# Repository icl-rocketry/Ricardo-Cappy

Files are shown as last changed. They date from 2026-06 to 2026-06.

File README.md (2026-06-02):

Hi. Welcome to the repo for Ricardo-Cappy.

Ricardo-Cappy is a custom HAT (Hardware Attached on Top) for the Raspberry Pi 5 to be used on the Payload lander for the 2026 ICLR launch.

It contains IMU sensors based on Ricardo-PickleRick, wirecutter modules, motor drivers for deploying landing legs, GPS and Radio capabilities as well as power systems for both the Raspberry Pi and the onboard components.

Contents:

-Hardware - contains the KiCad schematics and PCB layouts for Ricardo-Cappy, including symbols and footprints for parts not in the ICLR library. This is necessary for viewing and editing the KiCad files on your own device. 

To use the hardware files:
1. Install the ICLR symbol and footprint library (see their repo for detailed instructions, I forgot the link but you can use google)
2. Clone the repository onto your computer.
3. Install my custom libraries into KiCad (see instructions in KiCad documentation)

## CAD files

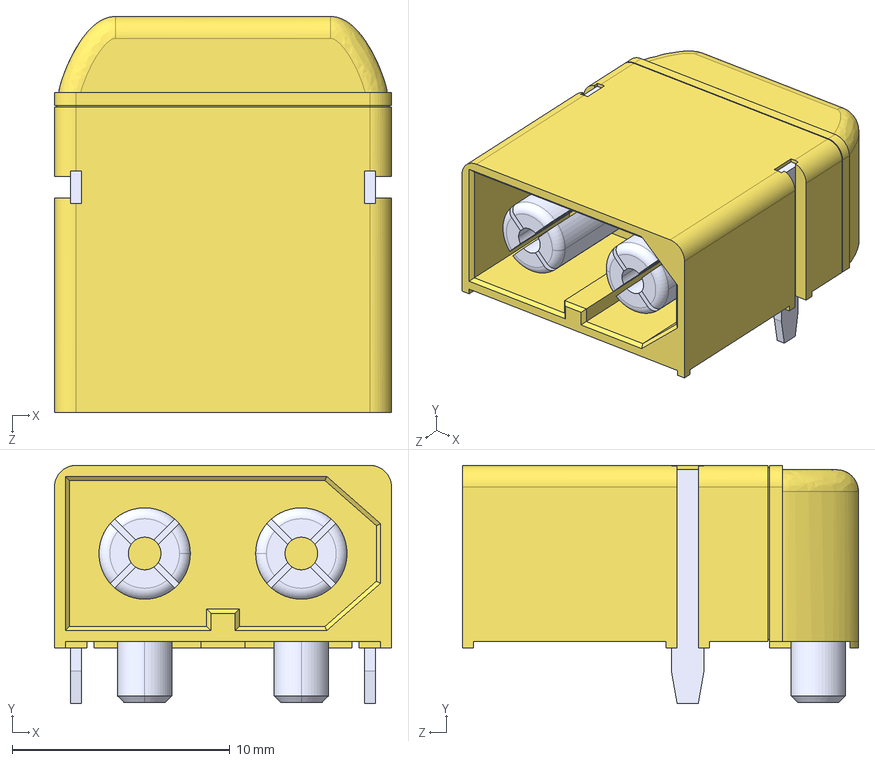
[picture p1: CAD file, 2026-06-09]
Hardware/XT60PW-M--3DModel-STEP-740395.STEP
15.5 x 10.9 x 18.2 mm

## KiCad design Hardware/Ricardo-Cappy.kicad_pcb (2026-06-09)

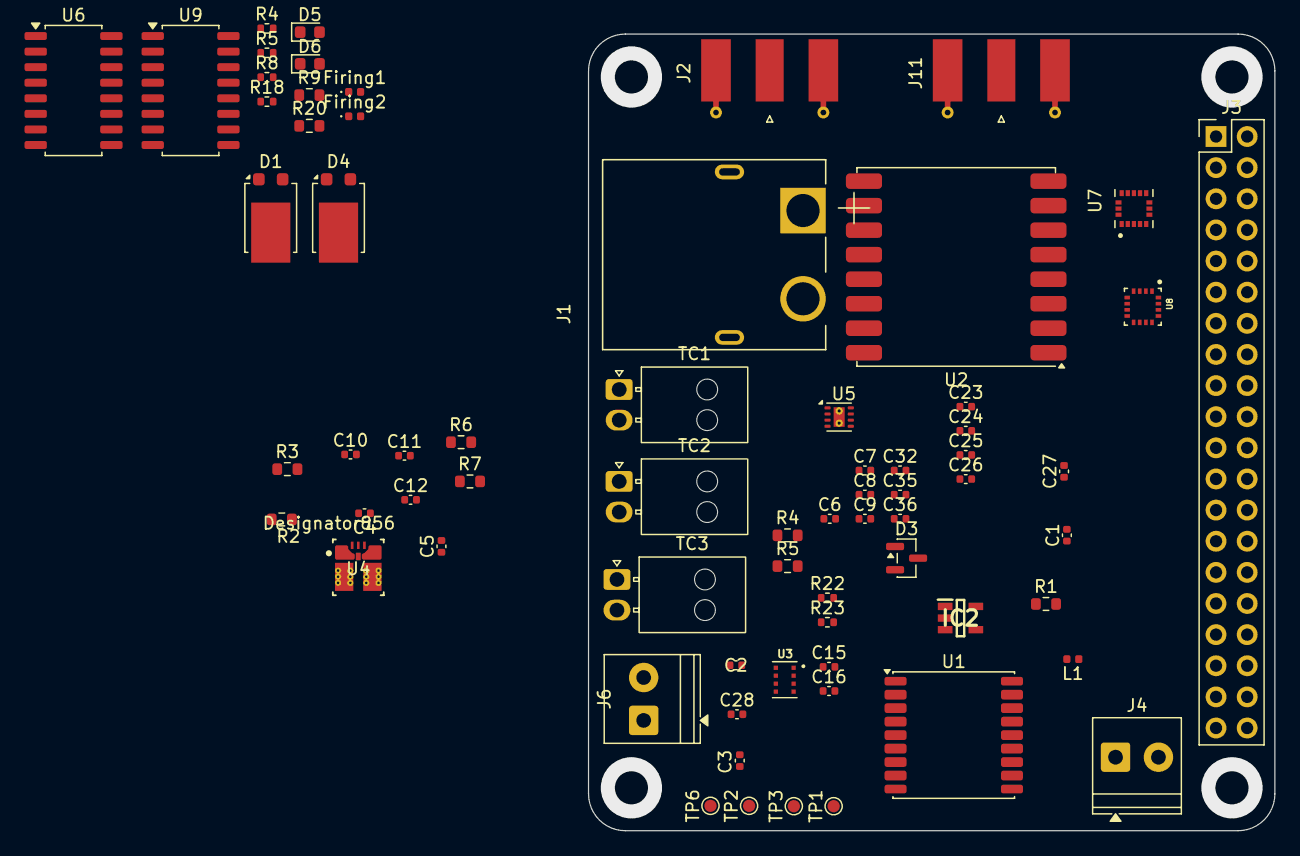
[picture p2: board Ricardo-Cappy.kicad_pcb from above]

Board: 2 copper layers, 56.0 x 65.0 mm, 69 parts (0 on the bottom side), 47 nets, no tracks yet.

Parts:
C1, C6, C12, C24: 10nF; C_0402_1005Metric
C2, C10, C27, C35: 10uF; C_0402_1005Metric
C3, C11, C15, C16, C36: 100nF; C_0402_1005Metric
C4, C8: 10pF; C_0402_1005Metric
C5: 47uF; C_0402_1005Metric
C7: 47pF; C_0402_1005Metric
C9, C28: 1uF; C_0402_1005Metric
C23: 0.47uF; C_0402_1005Metric
C25: 0.1uF; C_0402_1005Metric
C26, C32: 2.2uF; C_0402_1005Metric
D1, D4: DST1550S; TO-277B
D3: MMBZ6V2ALT1G; SOT-23
D5, D6: RED_LED; LED_0603_1608Metric
Firing1, Firing2: EMERALD_LED; LED_0402_1005Metric
IC2: AP2205-W5-7; SOT95P282X145-5N
J1: XT60PW-M; AMASS_XT60PW-M
J2, J11: Conn_Coaxial; SMA_Molex_73251-1153_EdgeMount_Horizontal
J3: Conn_02x20_Odd_Even; PinHeader_2x20_P2.54mm_Vertical
J4, J6: Conn_01x02_Male; TerminalBlock_Phoenix_PT-1,5-2-3.5-H_1x02_P3.50mm_Horizontal
L1: 27nH; L_0402_1005Metric
R1: 10; R_0603_1608Metric
R2: 226K; R_0603_1608Metric
R3, R5: 30k; R_0603_1608Metric
R4, R8: 10K; R_0402_1005Metric
R4#2: 226k; R_0603_1608Metric
R5#2, R18: 120; R_0402_1005Metric
R6: 31.6k; R_0603_1608Metric
R7: 10k; R_0603_1608Metric
R9, R20: 120; R_0603_1608Metric
R22: 49.9k; R_0402_1005Metric
R23: 150k; R_0402_1005Metric
TC1: Motor Out; Molex_Nano-Fit_105313-xx02_1x02_P2.50mm_Horizontal
TC2: PYRO_1_OUT; Molex_Nano-Fit_105313-xx02_1x02_P2.50mm_Horizontal
TC3: PYRO_2_OUT; Molex_Nano-Fit_105313-xx02_1x02_P2.50mm_Horizontal
TP1: GPS_RESET; TestPoint_Pad_D1.0mm
TP2, TP3, TP6: TestPoint; TestPoint_Pad_D1.0mm
U1: MAX-M10S; ublox_MAX
U2: RFM95W-868S2; HOPERF_RFM9XW_SMD
U3: DPS368; XDCR_DPS310
U4: TPSM863257RDXR; RDX0007A-MFG
U5: DRV8212P; WSON-8-1EP_2x2mm_P0.5mm_EP0.9x1.6mm_ThermalVias
U6, U9: LTV-247; SOP-16_4.4x10.4mm_P1.27mm
U7: ICM-20608-G; PQFN50P300X300X80-16N
U8: MMC5983MA; PQFN50P300X300X100-16N

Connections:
+3V3: C2.1, C3.1, C15.1, C16.1, C24.1, C25.1, C26.1, C28.1, J3.1, U1.6 (V_BCKP), U1.7 (VCC_IO), U1.8 (VCC), U2.13 (3.3V), U3.6 (VDDIO), U3.8 (VDD), U5.8 (VCC), U6.10, U7.1 (VDDIO), U7.16 (VDD), U8.2 (VDD), U8.13 (VDDIO), U9.10
+5.1V: C4.1, C5.1, J3.2, J3.4, R2.1, U4.3 (VOUT), U5.1 (VM)
+5.5V: C9.1, C35.1, C36.1, IC2.1 (VIN), IC2.3 (EN)
+5V: C7.1, C8.1, C32.1, D3.1 (K), IC2.5 (VOUT), R4#2.1, R23.2
/BARO_CS: J3.22, U3.2 (~CSB)
/Cont0: J3.8, R20.1, U6.9
/Cont1: J3.28, R9.1, U9.9
/DeployPWR: C10.1, C11.1, J1.1 (+), J4.1, J6.1, R6.1, TC2.1 (+), TC3.1 (+), U4.1 (VIN)
/GPS/RXD: TP2.1 (1_1), U1.3 (RXD)
/GPS/TXD: TP6.1 (1_1), U1.2 (TXD)
/IMU1_CS: J3.16, U7.5 (CS)
/LORA_CS: J3.15, U2.5 (NSS)
/LORA_INT: J3.13, U2.14 (DIO0)
/LORA_RESET: J3.11, U2.6 (RESET)
/MAG_CS: J3.18, U8.4 (~SPI_CS)
/MOTOR_PWM1: J3.32, U5.6 (IN1)
/MOTOR_PWM2: J3.33, U5.5 (IN2)
/Nuke 0: Firing1.2 (A), J3.36, R4.1
/Nuke 1: Firing2.2 (A), J3.10, R8.1
/PI_MISO: J3.21, U2.2 (MISO), U7.4 (AD0/SDO), U8.5 (SPI_SDO)
/PI_MISO_1: J3.35, U3.5 (SDO)
/PI_MOSI: J3.19, U2.3 (MOSI), U7.3 (SDA/SDI), U8.16 (SDA/SPI_SDI)
/PI_MOSI_1: J3.38, U3.3 (SDI)
/PI_SCLK: J3.23, U2.4 (SCK), U7.2 (SCL/SCLK), U8.1 (SCL/SPI_SCK)
/PI_SCLK_1: J3.40, U3.4 (SCK)
/PPS: J3.31, TP3.1 (1_1), U1.4 (TIMEPULSE)
/SCL: J3.5, U1.17 (SCL)
/SDA: J3.3, U1.16 (SDA)
GND: C1.2, C2.2, C3.2, C5.2, C6.2, C7.2, C9.2, C10.2, C11.2, C12.2, C15.2, C16.2, C23.2, C24.2, C25.2, C26.2, C27.2, C28.2, C32.2, C35.2, C36.2, D3.3 (A), D5.1 (K), D6.1 (K), IC2.2 (GND), J1.2 (-), J2.2 (Ext), J3.6, J3.9, J3.14, J3.20, J3.25, J3.30, J3.34, J3.39, J11.2 (Ext), R3.2, R4.2, R5.2, R5#2.2, R7.2, R8.2, R18.2, R22.1, U1.1 (GND), U1.10 (GND), U1.12 (GND), U2.1 (GND), U2.8 (GND), U2.10 (GND), U3.1 (GND), U3.7 (GND), U4.4 (PGND), U5.4 (GND), U5.9 (GND), U7.8 (FSYNC), U7.9 (GND), U7.10 (GND), U7.11 (GND), U7.12 (GND), U7.13 (GND), U7.15 (GND), U8.9 (GND), U8.11 (GND)
unnamed: C1.1, L1.1, R1.1
unnamed: D4.1 (A), D4.2 (A), J6.2, TC3.2 (-), U9.7
unnamed: D5.2 (A), R20.2
unnamed: D6.2 (A), R9.2
unnamed: D1.1 (A), D1.2 (A), J4.2, TC2.2 (-), U6.7
unnamed: Firing1.1 (K), R18.1
unnamed: Firing2.1 (K), R5#2.1
unnamed: IC2.4 (ADJ/NC), R22.2, R23.1
unnamed: J2.1 (In), L1.2, U1.11 (RF_IN)
unnamed: J11.1 (In), U2.9 (ANT)
unnamed: TC1.1 (+), U5.3 (OUT2)
unnamed: TC1.2 (-), U5.2 (OUT1)
unnamed: R1.2, U1.14 (VCC_RF)
unnamed: TP1.1 (1_1), U1.9 (~RESET)
unnamed: C6.1, C12.1, R6.2, R7.1, U4.6 (EN)
unnamed: C4.2, C8.2, R2.2, R3.1, R4#2.2, R5.1, U4.7 (FB)
unnamed: C23.1, U7.14 (REGOUT)
unnamed: C27.1, U8.10 (CAP)

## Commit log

2026-03-21 Relabelled some of the files
    [Pi-based PCB.kicad_pcb, Pi-based PCB.kicad_sch, pyro.kicad_sch]
2026-03-21 Renamed some files
    [Ricardo-Cappy.kicad_pcb, Ricardo-Cappy.kicad_sch, imu.kicad_sch]
2026-03-21 Modified power
    [GPS.kicad_sch, Ricardo-Cappy.kicad_sch, barometer.kicad_sch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]
2026-03-21 Fixed power
    [Ricardo-Cappy.kicad_sch, motor_control.kicad_sch, pyro.kicad_sch]
2026-06-02 Enhance hardware section with usage instructions
    Expanded the hardware section to include details on symbols and footprints, and added instructions for using the hardware files.
2026-06-09 Corrected accidentally deleted connection, reorganised PCB layout (still very WIP)
    [Ricardo-Cappy.kicad_pcb, Ricardo-Cappy.kicad_sch, XT60PW-M--3DModel-STEP-740395.STEP]
